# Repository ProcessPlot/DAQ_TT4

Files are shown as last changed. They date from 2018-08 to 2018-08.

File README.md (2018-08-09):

# DAQ_TT4
A simple, yet powerful data acquisition circuit that is basically an arduino compatible shield to read a 16-bit [ADC_MAX1300](https://datasheets.maximintegrated.com/en/ds/MAX1300-MAX1301.pdf) through the SPI interface. The board is enlarged to fit into an aluminum enclosure and use BNC input jacks.

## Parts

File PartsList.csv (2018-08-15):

Qty | Value | Device | Package | Parts | Description | DIGIKEY | DIGIKEY_PLUG | DIGIKEY_RECP | MOUSER | MPN | MPN_PLUG | MPN_RECP
2 |  | LED0805_GREEN | LED_0805 | LED1, LED4 | LED - 574nm Diffused | 160-1423-1-ND |  |  |  | LTST-C171GKT
1 |  | TRANSISTOR_NPNMMBT3904L | SOT23 | T2 | Bipolar Transistor - BJT NPN GENERAL PURPOSE | MMBT3904LT1GOSCT-ND |  |  |  | MMBT3904LT1G
8 |  | TSV14VAC_18VDC | 0805_SMD | U$2, U$3, U$4, U$6, U$8, U$9, U$12, U$13 |  | 478-6867-1-ND |  |  |  | VCAS08LC18A500DP
9 | 0.1uF | CAPACITOR0.1U_50V | 0805_SMD | C1, C10, C12, C13, C14, C15, C16, C29, C30 | Capacitor (non polarity) | 399-1176-1-ND |  |  |  | C0805C104M5UACTU
8 | 15 | RESISTOR15_0805 | 0805_SMD | R4, R5, R6, R7, R12, R14, R15, R17 | Resistor 1MOhms | 311-15.0CRCT-ND |  |  |  | RC0805FR-0715RL
8 | 1X2_HEADER1X2 | 1X2_HEADER1X2 | 1X2_HEADER | U$10, U$11, U$14, U$15, U$16, U$17, U$18, U$19 |  | WM4000-ND |  |  |  | 0022032021
1 | 2.2n | CAPACITOR2.2N_0805 | 0805_SMD | C22 | Capacitor (non polarity) | 399-1151-1-ND |  |  |  | C0805C222K5RACTU
2 | 220 | RESISTOR220_0805 | 0805_SMD | R1, R3 | Resistor 1MOhms | 311-220CRCT-ND |  |  |  | RC0805FR-07220RL
1 | 33k | RESISTOR33K_0805 | 0805_SMD | R16 | Resistor 1MOhms | 311-33.0KCRCT-ND |  |  |  | RC0805FR-0733KL
1 | 5.1k | RESISTOR5.1K_0805 | 0805_SMD | R13 | Resistor 1MOhms | 311-5.10KCRCT-ND |  |  |  | RC0805FR-075K1L
1 | ADC | ADC | LS_ELECTRIC_HTSSOP24-PAD | IC3 | 4/8 Channel 16bit ADC with 4 wire SPI | 700-MAX1300AEUG+ |  |  |  | MAX1300AEUG+
1 | ADUM3154 | ADUM3154 | SSOP_20 | U$5 |  | ADUM3154ARSZ-RL7CT-ND |  |  |  | ADUM3154ARSZ-RL7
1 | ARDUINOR3-DIMENSION | ARDUINOR3-DIMENSION | ARDUINOR3 | U4 | This is a new object for the new Arduino R3 - with extra pins that you may want to use (such as IOref, and duplicated A4/A5
1 | CG4 | BNC_INVBNC_INVERT | BNC | U$36 |  |  |  |  | 523-31-5431-10RFX | 031-5431-10RFX
1 | CH1 | BNC_INVBNC_INVERT | BNC | U$34 |  |  |  |  | 523-31-5431-10RFX | 031-5431-10RFX
1 | CH2 | BNC_INVBNC_INVERT | BNC | U$1 |  |  |  |  | 523-31-5431-10RFX | 031-5431-10RFX
1 | CH3 | BNC_INVBNC_INVERT | BNC | U$35 |  |  |  |  | 523-31-5431-10RFX | 031-5431-10RFX
1 | OPTOCOUPLER5KV_TOSHIBA | OPTOCOUPLER5KV_TOSHIBA | SO6L | OP1 | High Speed Optocoupler 5MBd 1Ch 1.6mA | TLP2745(TPECT-ND |  |  |  | TLP2745(TP,E
1 | POWER_SUPPLY_SINGLE5VIN_5VOUT | POWER_SUPPLY_SINGLE5VIN_5VOUT | SMT-R1SE-0505 | U$7 | 1kV/1W - 5Vin/5Vout | 945-1659-1-ND |  |  |  | R1SE-0505-R
1 | TB | TERMINAL_BLOCK_10PHOENIX_10 | TB_10P | U$40 |  |  | 277-5742-ND | 277-5950-ND |  |  | 1778069 | 1776582

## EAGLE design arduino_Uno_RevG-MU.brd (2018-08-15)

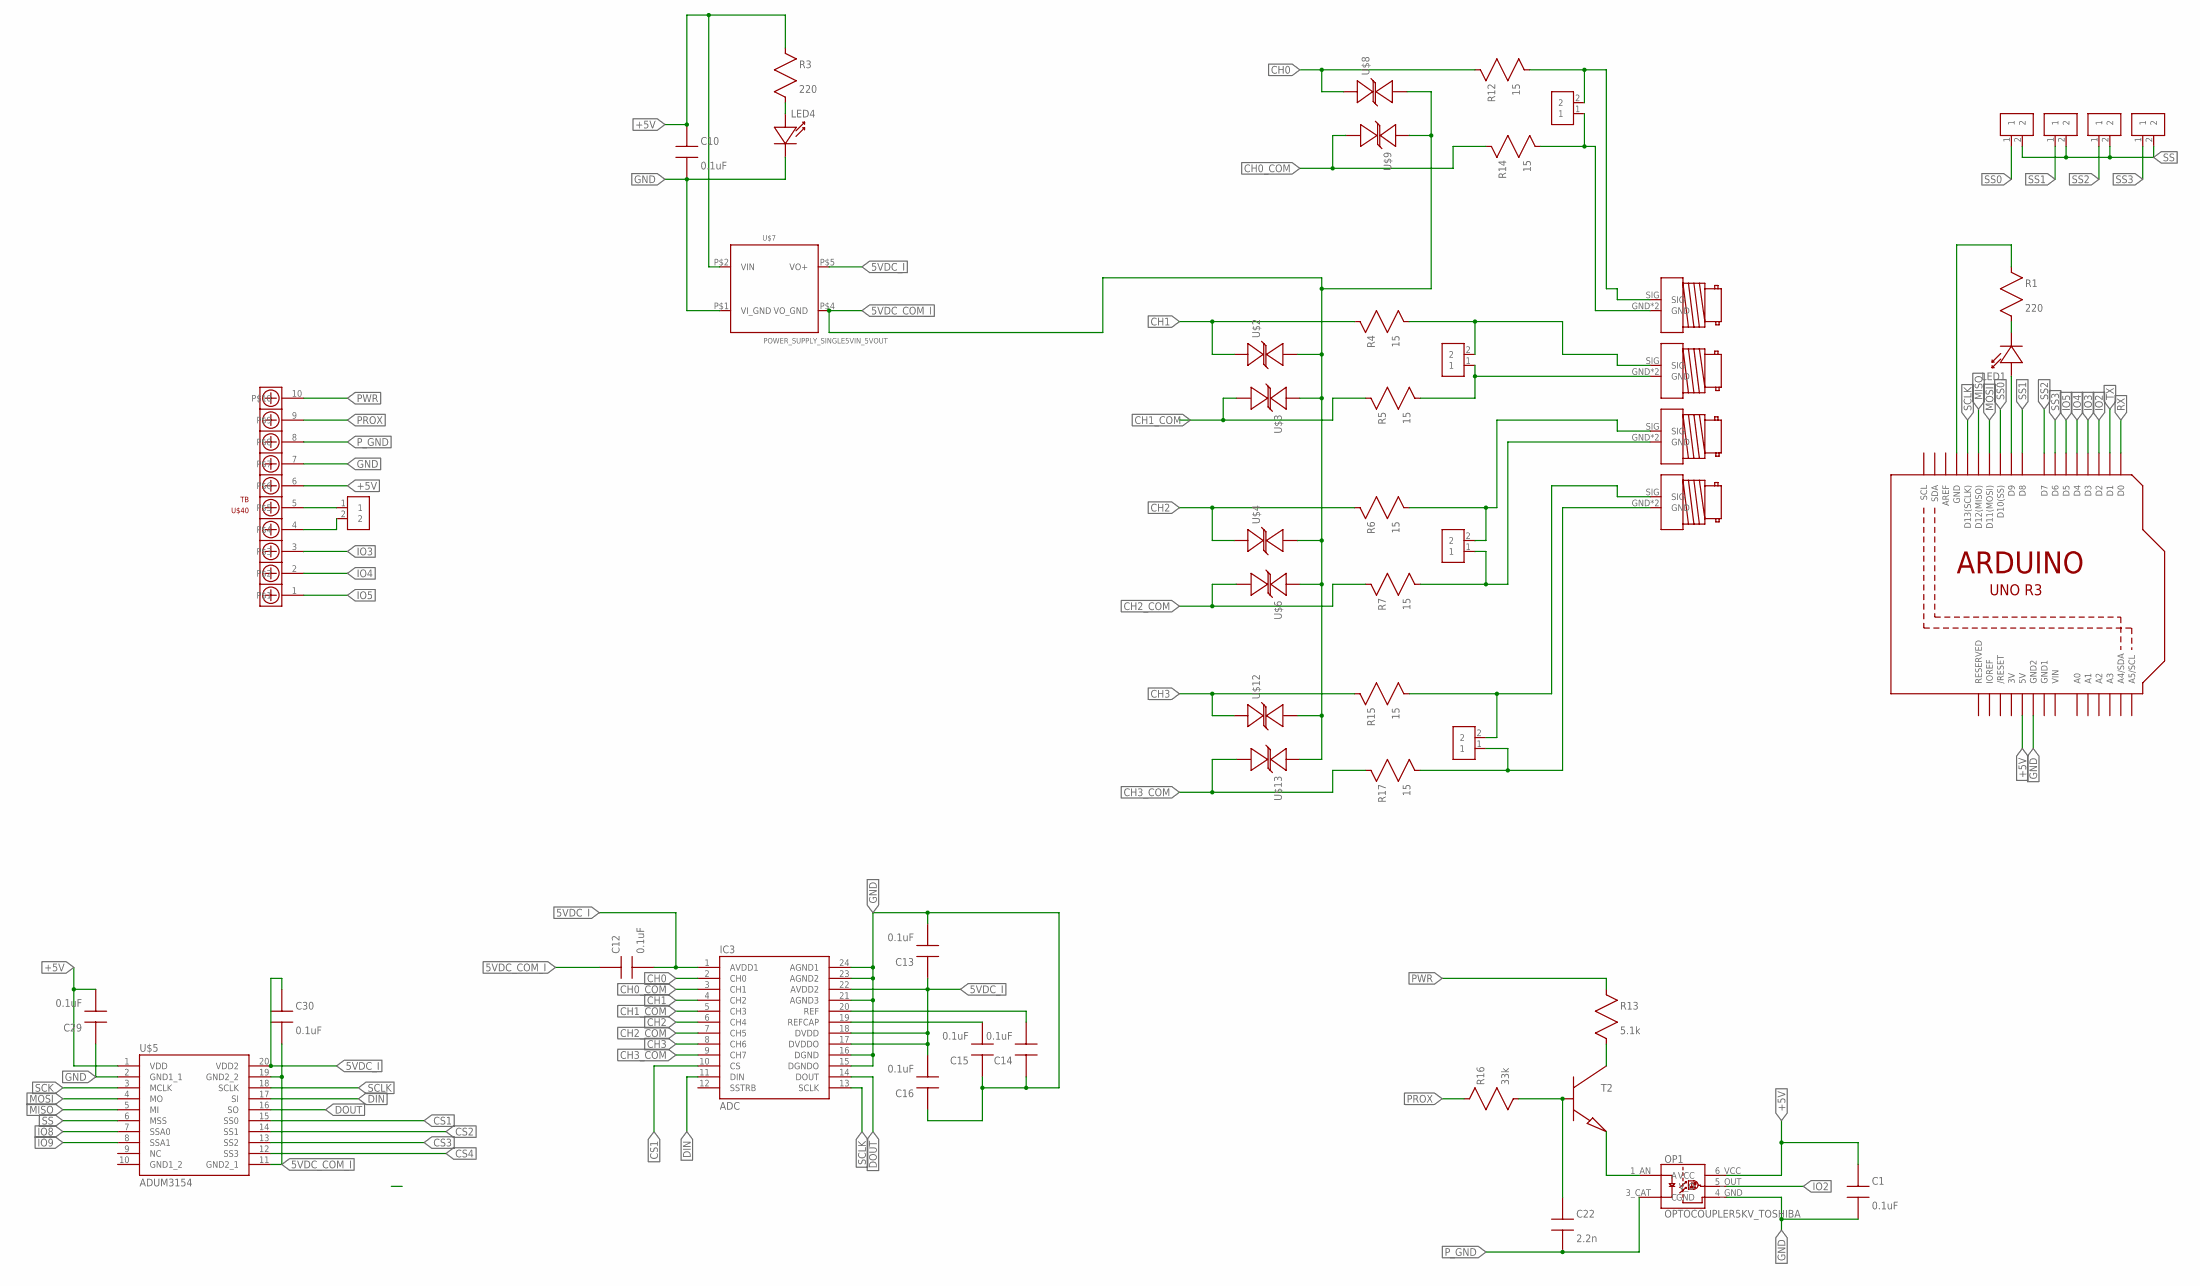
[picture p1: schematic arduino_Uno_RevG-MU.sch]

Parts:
C1, C10, C12, C13, C14, C15, C16, C29, C30: 0.1uF; 0805_SMD
C22: 2.2n; 0805_SMD
IC3: ADC; LS_ELECTRIC_HTSSOP24-PAD
LED1, LED4: LED0805_GREEN; LED_0805
OP1: OPTOCOUPLER5KV_TOSHIBA; SO6L
R1, R3: 220; 0805_SMD
R4, R5, R6, R7, R12, R14, R15, R17: 15; 0805_SMD
R13: 5.1k; 0805_SMD
R16: 33k; 0805_SMD
T2: TRANSISTOR_NPNMMBT3904L; SOT23
U4: ARDUINOR3-DIMENSION; ARDUINOR3
U$1: CH2; BNC
U$2, U$3, U$4, U$6, U$8, U$9, U$12, U$13: TSV14VAC_18VDC; 0805_SMD
U$5: ADUM3154; SSOP_20
U$7: POWER_SUPPLY_SINGLE5VIN_5VOUT; SMT-R1SE-0505
U$10, U$11, U$14, U$15, U$16, U$17, U$18, U$19, U$20: 1X2_HEADER1X2; 1X2_HEADER
U$34: CH1; BNC
U$35: CH3; BNC
U$36: CG4; BNC
U$40: TB; TB_10P

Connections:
3V: U4.3V
5VDC_COM_I: C12.1 (A), C30.2 (B), U$2.2 (GND), U$3.1 (+), U$4.2 (GND), U$5.11 (GND2_1), U$5.19 (GND2_2), U$6.1 (+), U$7.P$4 (VO_GND), U$8.2 (GND), U$9.1 (+), U$12.2 (GND), U$13.1 (+)
5VDC_I: C12.2 (B), C13.1 (A), C16.2 (B), C30.1 (A), IC3.1 (AVDD1), IC3.17 (DVDDO), IC3.18 (DVDD), IC3.22 (AVDD2), U$5.20 (VDD2), U$7.P$5 (VO+)
+5V: C1.1 (A), C10.1 (A), C29.2 (B), OP1.6_VCC (VCC), R3.1 (A), U4.5V, U$5.1 (VDD), U$7.P$2 (VIN), U$40.6
CH0: IC3.2 (CH0), R12.1 (A), U$8.1 (+)
CH0_COM: IC3.3 (CH1), R14.1 (A), U$9.2 (GND)
CH1: IC3.4 (CH2), R4.1 (A), U$2.1 (+)
CH1_COM: IC3.5 (CH3), R5.1 (A), U$3.2 (GND)
CH2: IC3.6 (CH4), R6.1 (A), U$4.1 (+)
CH2_COM: IC3.7 (CH5), R7.1 (A), U$6.2 (GND)
CH3: IC3.8 (CH6), R15.1 (A), U$12.1 (+)
CH3_COM: IC3.9 (CH7), R17.1 (A), U$13.2 (GND)
CS1: IC3.10 (CS), U$5.15 (SS0)
CS2: U$5.14 (SS1)
CS3: U$5.13 (SS2)
CS4: U$5.12 (SS3)
DIN: IC3.11 (DIN), U$5.17 (SI)
DOUT: IC3.14 (DOUT), U$5.16 (SO)
GND: C1.2 (B), C10.2 (B), C13.2 (B), C14.1 (A), C15.1 (A), C16.1 (A), C29.1 (A), IC3.15 (DGNDO), IC3.16 (DGND), IC3.21 (AGND3), IC3.23 (AGND2), IC3.24 (AGND1), LED4.C (-), OP1.4_GND (GND), R1.1 (A), U4.GND, U4.GND2, U$5.2 (GND1_1), U$7.P$1 (VI_GND), U$40.7
GND1: U4.GND1
IO2: OP1.5_OUT (V_O), U4.D2
IO3: U4.D3, U$40.3
IO4: U4.D4, U$40.2
IO5: U4.D5, U$40.1
IO8: U$5.7 (SSA0)
IO9: U$5.8 (SSA1)
MISO: U4.D12 (D12(MISO)), U$5.5 (MI)
MOSI: U4.D11 (D11(MOSI)), U$5.4 (MO)
unnamed: LED1.C (-), R1.2 (B)
unnamed: LED1.A (+), U4.D9
unnamed: U$20.2, U$40.4
unnamed: U$20.1, U$40.5
unnamed: LED4.A (+), R3.2 (B)
unnamed: C14.2 (B), IC3.20 (REF)
unnamed: C15.2 (B), IC3.19 (REFCAP)
unnamed: R4.2 (B), U$1.SIG, U$11.2
unnamed: R5.2 (B), U$1.GND, U$1.GND_INV (GND), U$11.1
unnamed: R15.2 (B), U$19.2, U$36.SIG
unnamed: R17.2 (B), U$19.1, U$36.GND, U$36.GND_INV (GND)
unnamed: OP1.1_AN (A), T2.2 (E)
unnamed: R13.2 (B), T2.3 (C)
unnamed: C22.1 (A), R16.2 (B), T2.1 (B)
unnamed: R12.2 (B), U$10.2, U$34.SIG
unnamed: R14.2 (B), U$10.1, U$34.GND, U$34.GND_INV (GND)
unnamed: R6.2 (B), U$18.2, U$35.SIG
unnamed: R7.2 (B), U$18.1, U$35.GND, U$35.GND_INV (GND)
PROX: R16.1 (A), U$40.9
PWR: R13.1 (A), U$40.10
P_GND: C22.2 (B), OP1.3_CAT (C), U$40.8
RX: U4.D0
SCK: U$5.3 (MCLK)
SCLK: IC3.13 (SCLK), U4.D13 (D13(SCLK)), U$5.18 (SCLK)
SS: U$5.6 (MSS), U$14.2, U$15.2, U$16.2, U$17.2
SS0: U4.D10 (D10(SS)), U$14.1
SS1: U4.D8, U$15.1
SS2: U4.D7, U$16.1
SS3: U4.D6, U$17.1
SSTRB: IC3.12 (SSTRB)
TX: U4.D1
VIN: U4.VIN

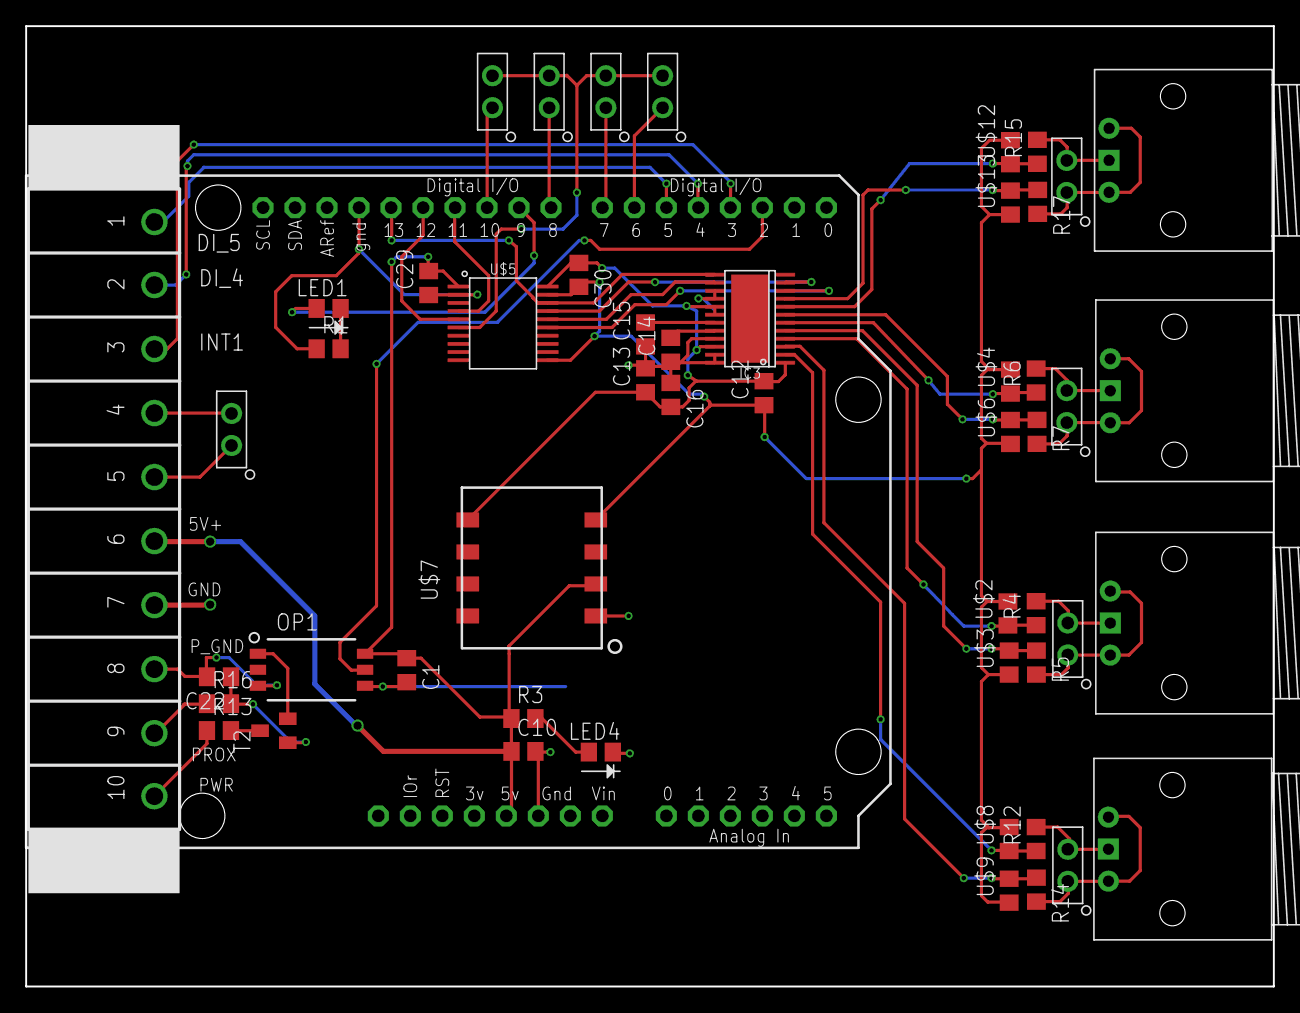
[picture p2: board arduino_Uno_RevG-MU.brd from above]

Board: 2 copper layers, 99.0 x 76.2 mm, 52 parts (0 on the bottom side), 48 nets.

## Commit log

2018-08-10 Initial eagle file
    [PartsList.csv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]
2018-08-15 First board order
    [arduino_Uno_RevG-MU.brd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]
2018-08-15 changed to 99mm board
    [arduino_Uno_RevG-MU.brd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]
